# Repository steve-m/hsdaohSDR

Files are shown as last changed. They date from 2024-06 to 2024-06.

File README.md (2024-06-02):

# hsdaohSDR - SDR prototype with 90 MHz bandwidth

This repository contains the KiCad hardware design files for the SDR prototype that was shown during the [hsdaoh](https://github.com/steve-m/hsdaoh) [talk at OsmoDevcon 2024](https://media.ccc.de/v/osmodevcon2024-200-low-cost-high-speed-data-acquisition-over-hdmi).

It is to be used with the 'sdr' branches of both the hsdaoh and hsdaoh-fpga repository:

https://github.com/steve-m/hsdaoh/tree/sdr

https://github.com/steve-m/hsdaoh-fpga/tree/sdr

hsdaohSDR PCB with RT720 tuner

hsdaohSDR

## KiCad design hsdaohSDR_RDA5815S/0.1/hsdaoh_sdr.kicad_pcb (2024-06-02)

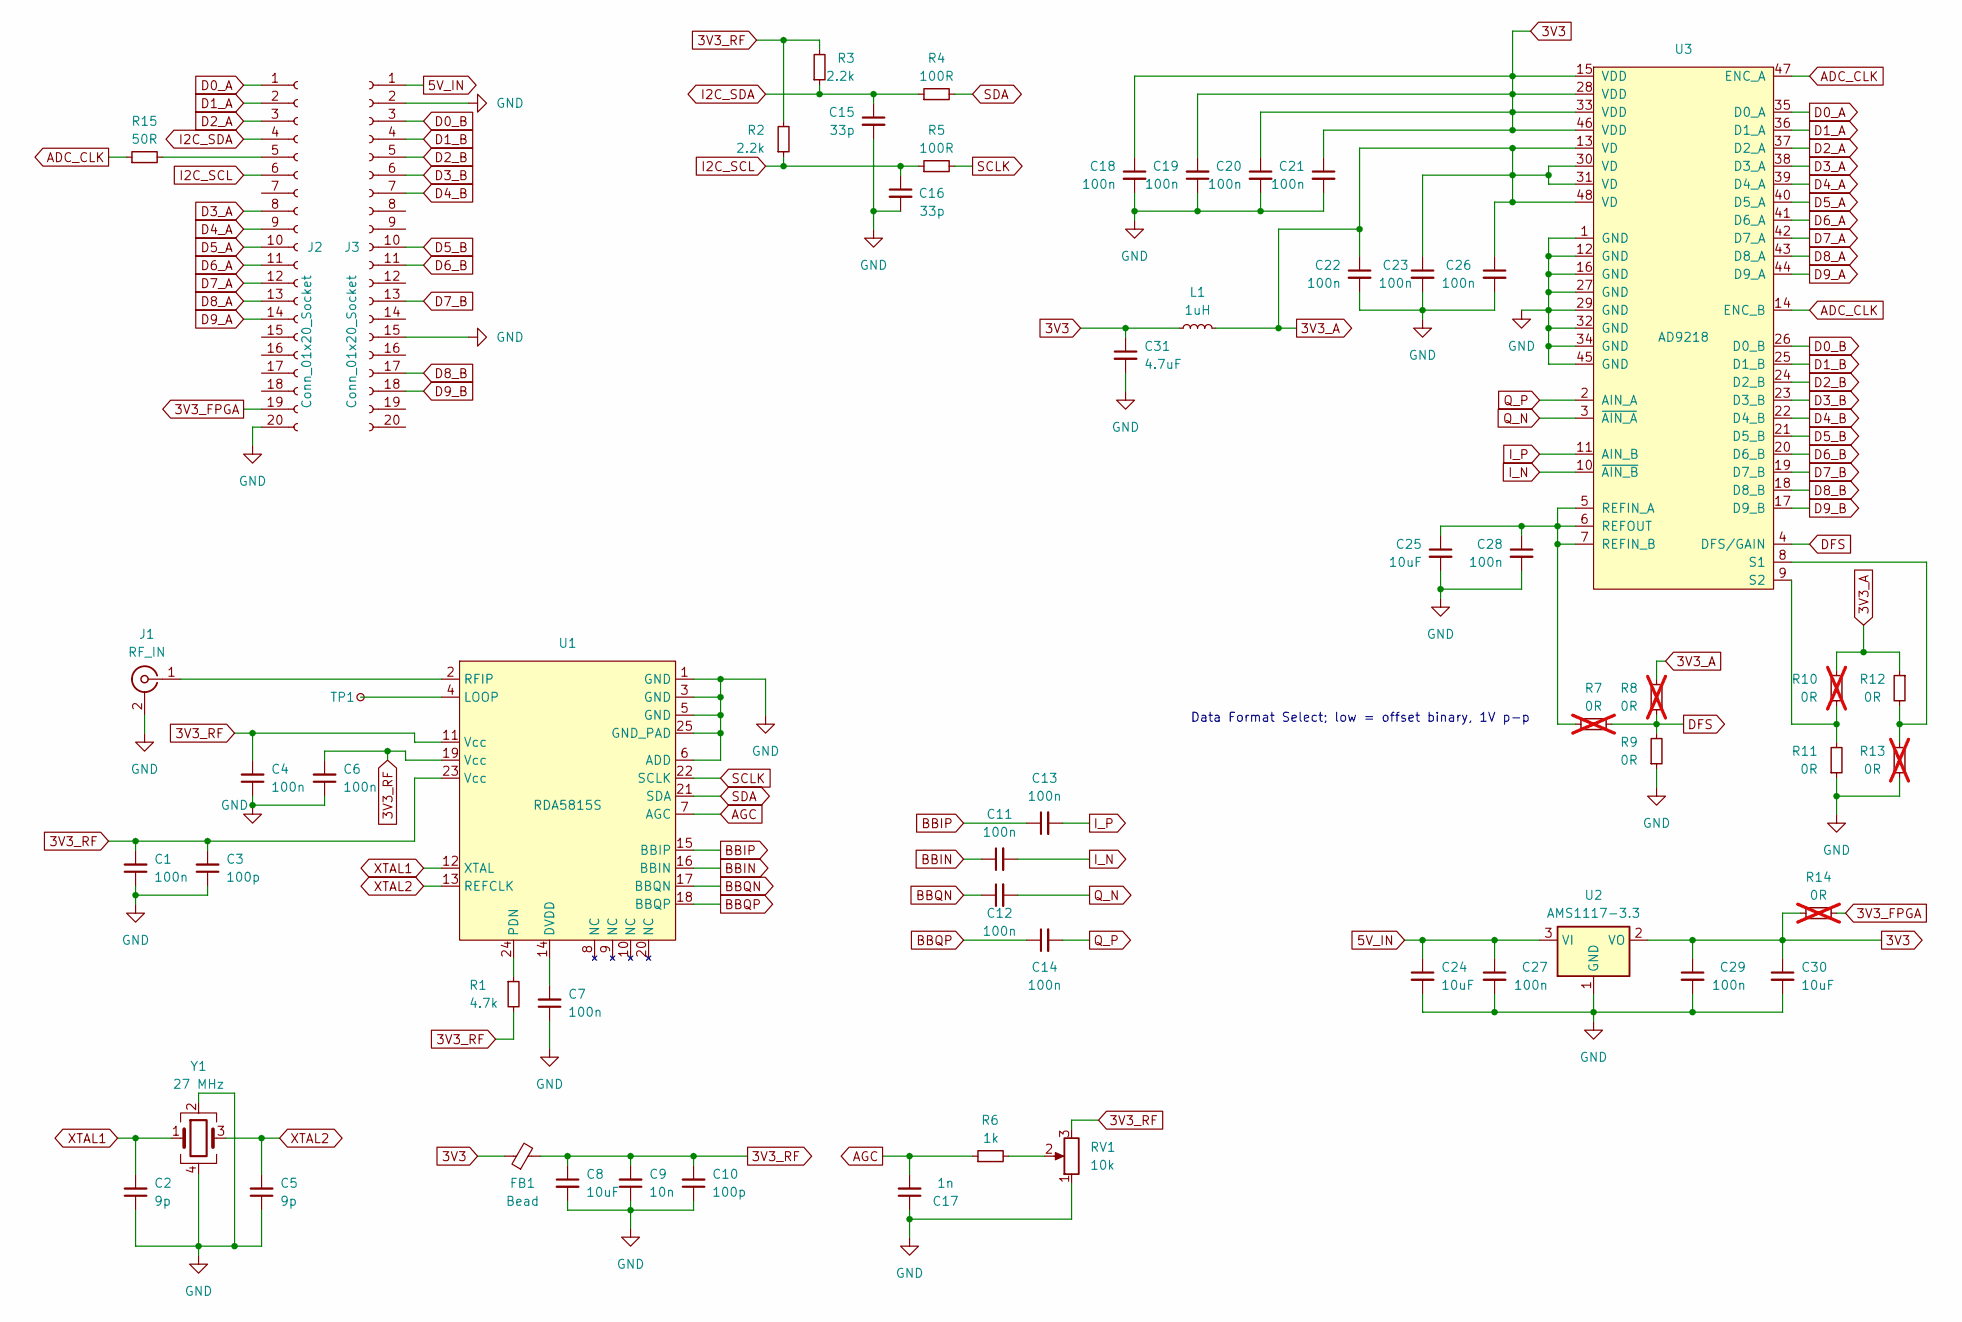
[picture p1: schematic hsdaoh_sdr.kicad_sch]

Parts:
C1, C4, C6, C7, C11, C12, C13, C14, C18, C19, C20, C21, C22, C23, C26, C27, C28, C29: 100n; C_0402_1005Metric
C2, C5: 9p; C_0402_1005Metric
C3, C10: 100p; C_0402_1005Metric
C8, C24, C30: 10uF; C_0805_2012Metric
C9: 10n; C_0402_1005Metric
C15, C16: 33p; C_0402_1005Metric
C17: 1n; C_0402_1005Metric
C25: 10uF; C_0603_1608Metric
C31: 4.7uF; C_0603_1608Metric
FB1: Bead; R_0603_1608Metric
J1: RF_IN; SMA_Molex_73251-1153_EdgeMount_Horizontal
J2, J3: Conn_01x20_Socket; PinSocket_1x20_P2.54mm_Vertical
L1: 1uH; L_0603_1608Metric
R1: 4.7k; R_0402_1005Metric
R2, R3: 2.2k; R_0402_1005Metric
R4, R5: 100R; R_0402_1005Metric
R6: 1k; R_0402_1005Metric
R7, R8, R10, R13: 0R; R_0402_1005Metric; not fitted
R9, R11, R12: 0R; R_0402_1005Metric
R14: 0R; R_0603_1608Metric; not fitted
R15: 50R; R_0402_1005Metric
RV1: 10k; Potentiometer_Bourns_TC33X_Vertical
TP1: TestPoint_Small; TestPoint_Pad_D1.0mm
U1: RDA5815S; QFN-24-1EP_4x4mm_P0.5mm_EP2.15x2.15mm_ThermalVias
U2: AMS1117-3.3; SOT-223-3_TabPin2
U3: AD9218; LQFP-48; Farnell 2376664
Y1: 27 MHz; Crystal_SMD_3225-4Pin_3.2x2.5mm

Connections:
3V3: C18.1, C19.2, C20.1, C21.1, C29.1, C30.1, C31.1, FB1.1, L1.1, R14.2, U2.2 (VO), U3.15 (VDD), U3.28 (VDD), U3.33 (VDD), U3.46 (VDD)
3V3_A: C22.1, C23.1, C26.1, L1.2, R8.2, R10.2, R12.1, U3.13 (VD), U3.30 (VD), U3.31 (VD), U3.48 (VD)
3V3_FPGA: J2.19, R14.1
3V3_RF: C1.2, C3.2, C4.2, C6.2, C8.1, C9.2, C10.2, FB1.2, R1.2, R2.2, R3.2, RV1.3, U1.11 (Vcc), U1.19 (Vcc), U1.23 (Vcc)
5V_IN: C24.1, C27.1, J3.1, U2.3 (VI)
ADC_CLK: R15.1, U3.14 (ENC_B), U3.47 (ENC_A)
AGC: C17.2, R6.1, U1.7 (AGC)
BBIN: C11.1, U1.16 (BBIN)
BBIP: C13.1, U1.15 (BBIP)
BBQN: C12.1, U1.17 (BBQN)
BBQP: C14.1, U1.18 (BBQP)
D0_A: J2.1, U3.35 (D0_A)
D0_B: J3.3, U3.26 (D0_B)
D1_A: J2.2, U3.36 (D1_A)
D1_B: J3.4, U3.25 (D1_B)
D2_A: J2.3, U3.37 (D2_A)
D2_B: J3.5, U3.24 (D2_B)
D3_A: J2.8, U3.38 (D3_A)
D3_B: J3.6, U3.23 (D3_B)
D4_A: J2.9, U3.39 (D4_A)
D4_B: J3.7, U3.22 (D4_B)
D5_A: J2.10, U3.40 (D5_A)
D5_B: J3.10, U3.21 (D5_B)
D6_A: J2.11, U3.41 (D6_A)
D6_B: J3.11, U3.20 (D6_B)
D7_A: J2.12, U3.42 (D7_A)
D7_B: J3.13, U3.19 (D7_B)
D8_A: J2.13, U3.43 (D8_A)
D8_B: J3.17, U3.18 (D8_B)
D9_A: J2.14, U3.44 (D9_A)
D9_B: J3.18, U3.17 (D9_B)
DFS: R7.1, R8.1, R9.2, U3.4 (DFS/GAIN)
GND: C1.1, C2.1, C3.1, C4.1, C5.1, C6.1, C7.1, C8.2, C9.1, C10.1, C15.2, C16.2, C17.1, C18.2, C19.1, C20.2, C21.2, C22.2, C23.2, C24.2, C25.2, C26.2, C27.2, C28.2, C29.2, C30.2, C31.2, J1.2 (Ext), J2.20, J3.2, J3.15, R9.1, R11.1, R13.2, RV1.1, U1.1 (GND), U1.3 (GND), U1.5 (GND), U1.6 (ADD), U1.25 (GND_PAD), U2.1 (GND), U3.1 (GND), U3.12 (GND), U3.16 (GND), U3.27 (GND), U3.29 (GND), U3.32 (GND), U3.34 (GND), U3.45 (GND), Y1.2, Y1.4
I2C_SCL: C16.1, J2.6, R2.1, R5.1
I2C_SDA: C15.1, J2.4, R3.1, R4.1
I_N: C11.2, U3.10 (~AIN_B)
I_P: C13.2, U3.11 (AIN_B)
unnamed: J1.1 (In), U1.2 (RFIP)
unnamed: J2.5, R15.2
unnamed: R6.2, RV1.2
unnamed: C7.2, U1.14 (DVDD)
unnamed: TP1.1, U1.4 (LOOP)
unnamed: R1.1, U1.24 (PDN)
unnamed: C25.1, C28.1, R7.2, U3.5 (REFIN_A), U3.6 (REFOUT), U3.7 (REFIN_B)
unnamed: R12.2, R13.1, U3.8 (S1)
unnamed: R10.1, R11.2, U3.9 (S2)
Q_N: C12.2, U3.3 (~AIN_A)
Q_P: C14.2, U3.2 (AIN_A)
SCLK: R5.2, U1.22 (SCLK)
SDA: R4.2, U1.21 (SDA)
XTAL1: C2.2, U1.12 (XTAL), Y1.1
XTAL2: C5.2, U1.13 (REFCLK), Y1.3

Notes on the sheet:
Data Format Select; low = offset binary, 1V p-p

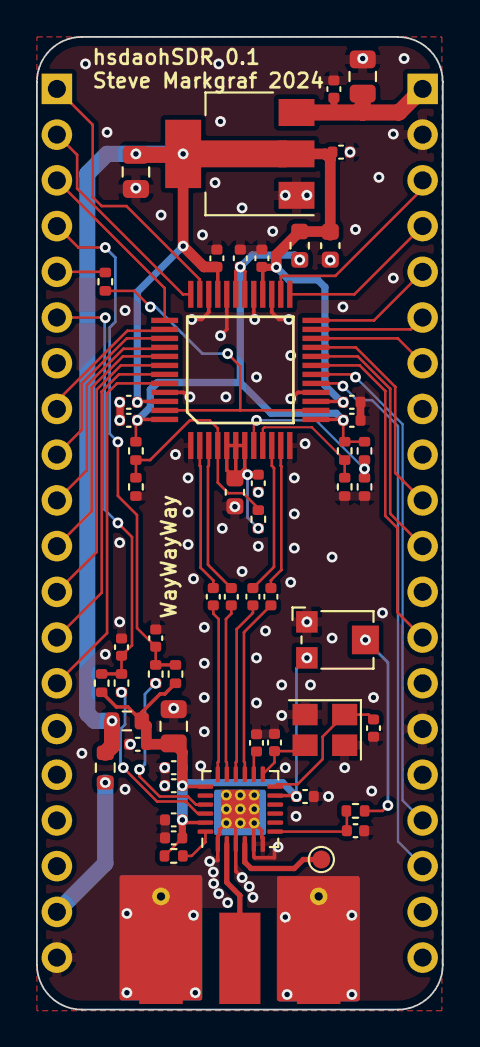
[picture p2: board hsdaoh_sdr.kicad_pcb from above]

Board: 2 copper layers, 22.5 x 54.0 mm, 57 parts (0 on the bottom side), 52 nets.
